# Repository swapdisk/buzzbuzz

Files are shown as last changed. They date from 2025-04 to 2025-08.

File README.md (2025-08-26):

# Game Show Buzzer Buttons

Just some files and code we used to mod these toy game show buzzer buttons. Not polished or even presentable for now. We'll make it better before we scale up production!

Each button connects using Bluetooth to the laptop presenting the game show. When a button is pressed, a keyboard event is sent, triggering a custom keyboard shortcut that runs the [`buzzer.sh`](./buzzer.sh) script. 

When activated, the script plays the buzzer sound and then uses [`hudkit`](https://github.com/anko/hudkit) to pop up an overlay on the laptop display showing which team buzzed in first. The buzz in from the losing team updates the overlay displaying the time difference.

## Photos

Behold our finished buzzer buttons being demonstrated with an example game show.
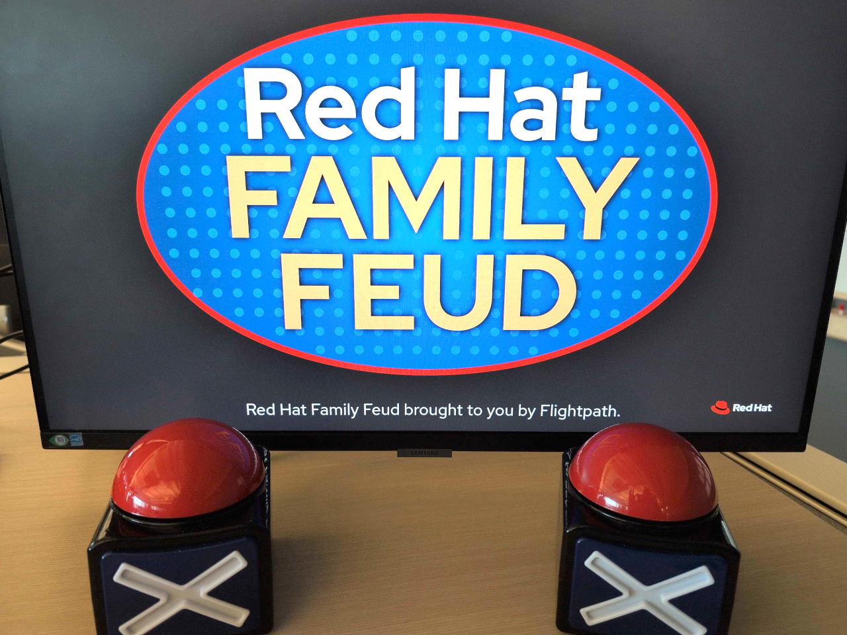
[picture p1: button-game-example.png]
Example game show use case


The back panel of each button sports a power switch that also serves as a Bluetooth pairing status indicator. Next to that is a USB-C port used for charging the internal battery.
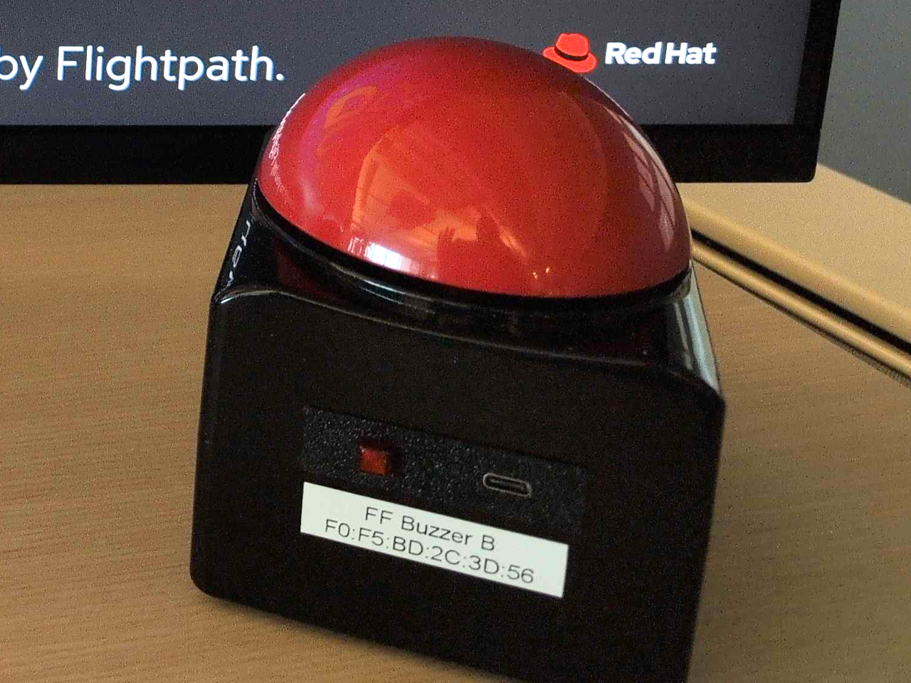
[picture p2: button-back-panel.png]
Back panel with power switch, status indicator and charging port


Here is a screenshot from [OpenSCAD](https://openscad.org/) showing the solid model used to 3D print the back panel and ESP32 card slot.
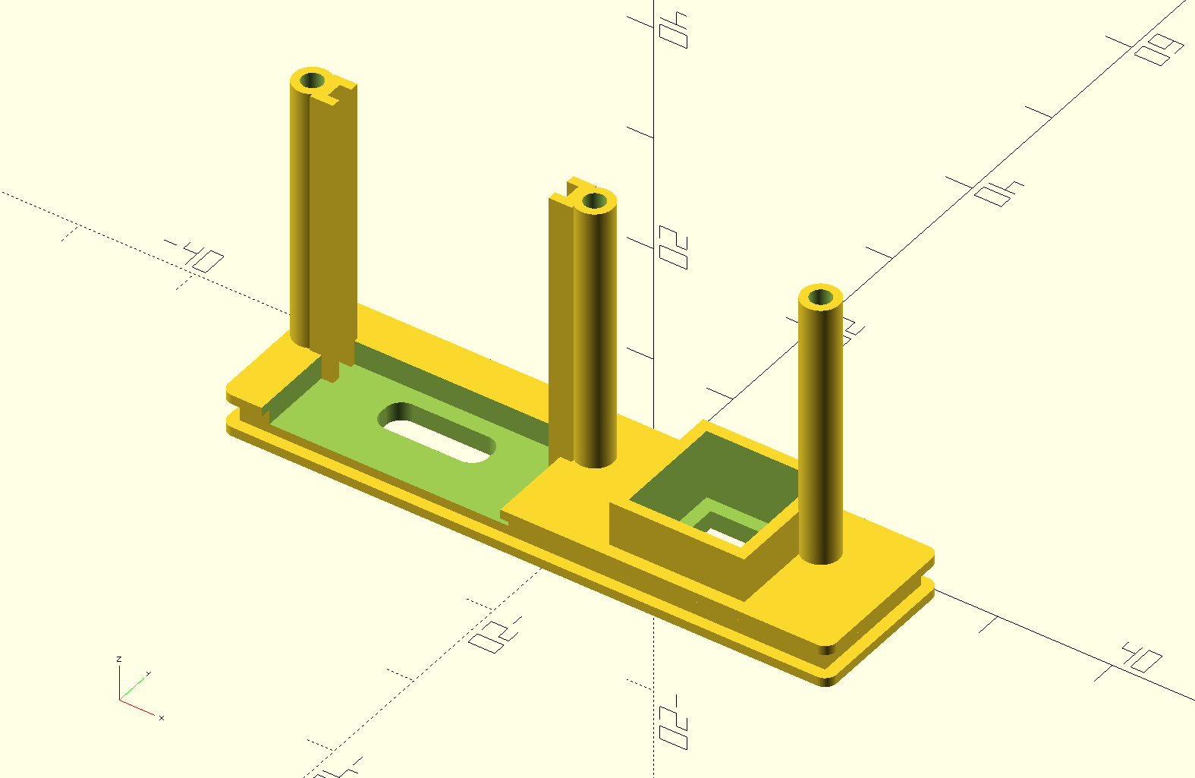
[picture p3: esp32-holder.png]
3D model of back panel with ESP32 card slot


## Licensing

MIT

See [LICENSE](LICENSE) to see the full text.

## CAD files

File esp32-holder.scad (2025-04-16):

$fn=120;

// face plate thick
fpt=0.80;
// face plate height
fph=14;
// face plate width
fpw=28;
// switch plate width
spw=28;
// face plate corner rad
fpc=1.0   ;
// slot thick
st=2.10;
// usb high
uh=1.60;
// board width
bw=20.80;
// board height
bh=25.10;
// usb dims
usbh=3.43; usbw=9.36; usbr=1.4;
// switch hole square
sh=7.45;
// switch hole depth
shd=1.55;
// switch body square
sb=9.78;

translate([-25, 0, 0]) difference() {
    union() {
        // switch plate front
        linear_extrude(fpt) hull() {
            translate([fpc, fpc, 0]) circle(fpc);
            translate([-fpc+spw, fpc, 0]) circle(fpc);
            translate([fpc, -fpc+fph, 0]) circle(fpc);
            translate([-fpc+spw, -fpc+fph, 0]) circle(fpc);
        }
        
        // slot rectangle
        translate([fpc, fpc, fpt]) cube([spw-fpc*2, fph-fpc*2, st]);
        
        // switch plate back
        translate([0, 0, fpt+st]) linear_extrude(fpt) hull() {
            translate([fpc, fpc, 0]) circle(fpc);
            translate([-fpc+spw, fpc, 0]) circle(fpc);
            translate([fpc, -fpc+fph, 0]) circle(fpc);
            translate([-fpc+spw, -fpc+fph, 0]) circle(fpc);
        }
        
        // switch support
        translate([(spw-sb-2)/2, (fph-sb-2)/2, shd]) cube([sb+2, sb+2, 6]);
    }
    
    // switch cavity
    translate([(spw-sh)/2, (fph-sh)/2, -1]) cube([sh, sh, 99]);
    translate([(spw-sb)/2, (fph-sb)/2, shd]) cube([sb, sb, 99]);
}

difference() {
    union() {
        // face plate front
        linear_extrude(fpt) hull() {
            translate([fpc, fpc, 0]) circle(fpc);
            translate([-fpc+fpw, fpc, 0]) circle(fpc);
            translate([fpc, -fpc+fph, 0]) circle(fpc);
            translate([-fpc+fpw, -fpc+fph, 0]) circle(fpc);
        }
        
        // slot rectangle
        translate([fpc, fpc, fpt]) cube([fpw-fpc*2, fph-fpc*2, st]);
        
        // face plate back
        translate([0, 0, fpt+st]) linear_extrude(fpt) hull() {
            translate([fpc, fpc, 0]) circle(fpc);
            translate([-fpc+fpw, fpc, 0]) circle(fpc);
            translate([fpc, -fpc+fph, 0]) circle(fpc);
            translate([-fpc+fpw, -fpc+fph, 0]) circle(fpc);
        }
    }
    
    // usb-c connector
    translate([(fpw-usbw)/2, (fph-usbh)/2, -1]) linear_extrude(99) hull() {
        translate([usbr, usbr, 0]) circle(usbr);
        translate([-usbr+usbw, usbr, 0]) circle(usbr);
        translate([usbr, -usbr+usbh, 0]) circle(usbr);
        translate([-usbr+usbw, -usbr+usbh, 0]) circle(usbr);
    }

    // board cavity
    translate([(fpw-bw)/2, -1.5+(fph-usbh)/2, uh]) cube([bw, 99, 99]);

    // debug
    //translate([0, 0, -1]) cube(5);
}

// board frame
aj=0.4+(fph-10)/2;
translate([-1.0+(fpw-bw)/2, fpc+aj, uh]) cube([1, 3.1, bh]);
translate([(fpw-bw)/2, fpc+aj, uh]) cube([1, 0.8, bh]);
translate([(fpw-bw)/2, fpc+2.3+aj, uh]) cube([1, 0.8, bh]);

translate([(fpw+bw)/2, fpc+aj, uh]) cube([1, 3.1, bh]);
translate([-1.0+(fpw+bw)/2, fpc+aj, uh]) cube([1, 0.8, bh]);
translate([-1.0+(fpw+bw)/2, fpc+2.3+aj, uh]) cube([1, 0.8, bh]);

// screw columns
c1=1.6;
c2=0.9;
translate([-1.9+(fpw-bw)/2, fpc+aj+1.5, uh]) difference() {
    cylinder(bh, c1, c1);
    cylinder(bh+1, c2, c2);
}
translate([1.9+(fpw+bw)/2, fpc+aj+1.5, uh+2]) difference() {
    cylinder(bh-2, c1, c1);
    cylinder(bh+1, c2, c2);
}
translate([-18, fpc+aj+1.5, uh]) difference() {
    cylinder(bh, c1, c1);
    cylinder(bh+1, c2, c2);
}
echo(-1.9+(fpw-bw)/2, 1.9+(fpw+bw)/2, -18);

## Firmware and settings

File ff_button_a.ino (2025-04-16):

/* 
 * Sample program for ESP32 acting as a Bluetooth keyboard
 * 
 * Copyright (c) 2019 Manuel Bl
 * 
 * Licensed under MIT License
 * https://opensource.org/licenses/MIT
 */

//
// This program lets an ESP32 act as a keyboard connected via Bluetooth.
// When a button attached to the ESP32 is pressed, it will generate the key strokes for a message.
//
// For the setup, a momentary button should be connected to pin 2 and to ground.
// Pin 2 will be configured as an input with pull-up.
//
// In order to receive the message, add the ESP32 as a Bluetooth keyboard of your computer
// or mobile phone:
//
// 1. Go to your computers/phones settings
// 2. Ensure Bluetooth is turned on
// 3. Scan for Bluetooth devices
// 4. Connect to the device called "ESP32 Keyboard"
// 5. Open an empty document in a text editor
// 6. Press the button attached to the ESP32

#define US_KEYBOARD 1

#include "BLEDevice.h"
#include "BLEHIDDevice.h"
#include "HIDTypes.h"
#include "HIDKeyboardTypes.h"


// Change the below values if desired
#define BUTTON_PIN 6
#define MESSAGE "a"
#define DEVICE_NAME "FF Buzzer A"
#define STATUS_LED 7

// Debounce and battery report timers
unsigned long debounceTime = 3000;
unsigned long lastBuzz = debounceTime;
unsigned long battReportTime = 15000;
unsigned long lastBattReport = battReportTime;
unsigned long nowTime;

// Return battery level as percent
int battLevel() {
  int battPct = (analogReadMilliVolts(0) - 1850) * 100 / 250;
  return ((battPct < 0) ? 0 : (battPct > 100) ? 100 : battPct);
}


// Forward declarations
void bluetoothTask(void*);
void typeText(const char* text);


bool isBleConnected = false;


void setup() {
    Serial.begin(115200);

    // Configure GPIO pins
    analogReadResolution(12);
    pinMode(BUTTON_PIN, INPUT_PULLUP);
    pinMode(STATUS_LED, OUTPUT);
    digitalWrite(STATUS_LED, HIGH);

    // start Bluetooth task
    xTaskCreate(bluetoothTask, "bluetooth", 20000, NULL, 5, NULL);
}


void loop() {
  // Get current timestamp
  nowTime = millis();

  // Bluetooth keyboard event
  if (isBleConnected && digitalRead(BUTTON_PIN) == LOW) {
    if (nowTime - lastBuzz > debounceTime) {
      // Debug output
      Serial.print("Sending keypress at ");
      Serial.println(nowTime);

      // Send key press and release events
      typeKustom(MESSAGE);
    }

    // Reset debounce timer
    lastBuzz = nowTime;
  }

  // Status blink logic
  // Slow short blink: Bluetooth connected
  // Quick long blink: Waiting for connection
  if (isBleConnected) {
    digitalWrite(STATUS_LED, (nowTime % 1500 > 100) ? LOW : HIGH);
  } else {
    digitalWrite(STATUS_LED, (nowTime % 500 > 400) ? LOW : HIGH);
  }
}


// Message (report) sent when a key is pressed or released
struct InputReport {
    uint8_t modifiers;	     // bitmask: CTRL = 1, SHIFT = 2, ALT = 4
    uint8_t reserved;        // must be 0
    uint8_t pressedKeys[6];  // up to six concurrenlty pressed keys
};

// Message (report) received when an LED's state changed
struct OutputReport {
    uint8_t leds;            // bitmask: num lock = 1, caps lock = 2, scroll lock = 4, compose = 8, kana = 16
};


// The report map describes the HID device (a keyboard in this case) and
// the messages (reports in HID terms) sent and received.
static const uint8_t REPORT_MAP[] = {
    USAGE_PAGE(1),      0x01,       // Generic Desktop Controls
    USAGE(1),           0x06,       // Keyboard
    COLLECTION(1),      0x01,       // Application
    REPORT_ID(1),       0x01,       //   Report ID (1)
    USAGE_PAGE(1),      0x07,       //   Keyboard/Keypad
    USAGE_MINIMUM(1),   0xE0,       //   Keyboard Left Control
    USAGE_MAXIMUM(1),   0xE7,       //   Keyboard Right Control
    LOGICAL_MINIMUM(1), 0x00,       //   Each bit is either 0 or 1
    LOGICAL_MAXIMUM(1), 0x01,
    REPORT_COUNT(1),    0x08,       //   8 bits for the modifier keys
    REPORT_SIZE(1),     0x01,       
    HIDINPUT(1),        0x02,       //   Data, Var, Abs
    REPORT_COUNT(1),    0x01,       //   1 byte (unused)
    REPORT_SIZE(1),     0x08,
    HIDINPUT(1),        0x01,       //   Const, Array, Abs
    REPORT_COUNT(1),    0x06,       //   6 bytes (for up to 6 concurrently pressed keys)
    REPORT_SIZE(1),     0x08,
    LOGICAL_MINIMUM(1), 0x00,
    LOGICAL_MAXIMUM(1), 0x65,       //   101 keys
    USAGE_MINIMUM(1),   0x00,
    USAGE_MAXIMUM(1),   0x65,
    HIDINPUT(1),        0x00,       //   Data, Array, Abs
    REPORT_COUNT(1),    0x05,       //   5 bits (Num lock, Caps lock, Scroll lock, Compose, Kana)
    REPORT_SIZE(1),     0x01,
    USAGE_PAGE(1),      0x08,       //   LEDs
    USAGE_MINIMUM(1),   0x01,       //   Num Lock
    USAGE_MAXIMUM(1),   0x05,       //   Kana
    LOGICAL_MINIMUM(1), 0x00,
    LOGICAL_MAXIMUM(1), 0x01,
    HIDOUTPUT(1),       0x02,       //   Data, Var, Abs
    REPORT_COUNT(1),    0x01,       //   3 bits (Padding)
    REPORT_SIZE(1),     0x03,
    HIDOUTPUT(1),       0x01,       //   Const, Array, Abs
    END_COLLECTION(0)               // End application collection
};


BLEHIDDevice* hid;
BLECharacteristic* input;
BLECharacteristic* output;

const InputReport NO_KEY_PRESSED = { };


/*
 * Callbacks related to BLE connection
 */
class BleKeyboardCallbacks : public BLEServerCallbacks {

    void onConnect(BLEServer* server) {
        isBleConnected = true;

        // Allow notifications for characteristics
        BLE2902* cccDesc = (BLE2902*)input->getDescriptorByUUID(BLEUUID((uint16_t)0x2902));
        cccDesc->setNotifications(true);

        Serial.println("Client has connected");
    }

    void onDisconnect(BLEServer* server) {
        isBleConnected = false;

        // Disallow notifications for characteristics
        BLE2902* cccDesc = (BLE2902*)input->getDescriptorByUUID(BLEUUID((uint16_t)0x2902));
        cccDesc->setNotifications(false);

        Serial.println("Client has disconnected");
    }
};


/*
 * Called when the client (computer, smart phone) wants to turn on or off
 * the LEDs in the keyboard.
 * 
 * bit 0 - NUM LOCK
 * bit 1 - CAPS LOCK
 * bit 2 - SCROLL LOCK
 */
 class OutputCallbacks : public BLECharacteristicCallbacks {
    void onWrite(BLECharacteristic* characteristic) {
        OutputReport* report = (OutputReport*) characteristic->getData();
        Serial.print("LED state: ");
        Serial.print((int) report->leds);
        Serial.println();
    }
};


void bluetoothTask(void*) {

    // initialize the device
    BLEDevice::init(DEVICE_NAME);
    BLEServer* server = BLEDevice::createServer();
    server->setCallbacks(new BleKeyboardCallbacks());

    // create an HID device
    hid = new BLEHIDDevice(server);
    input = hid->inputReport(1); // report ID
    output = hid->outputReport(1); // report ID
    output->setCallbacks(new OutputCallbacks());

    // set manufacturer name
    hid->manufacturer()->setValue("Maker Community");
    // set USB vendor and product ID
    hid->pnp(0x02, 0xe502, 0xa111, 0x0210);
    // information about HID device: device is not localized, device can be connected
    hid->hidInfo(0x00, 0x02);

    // Security: device requires bonding
    BLESecurity* security = new BLESecurity();
    security->setAuthenticationMode(ESP_LE_AUTH_BOND);

    // set report map
    hid->reportMap((uint8_t*)REPORT_MAP, sizeof(REPORT_MAP));
    hid->startServices();

    // advertise the services
    BLEAdvertising* advertising = server->getAdvertising();
    advertising->setAppearance(HID_KEYBOARD);
    advertising->addServiceUUID(hid->hidService()->getUUID());
    advertising->addServiceUUID(hid->deviceInfo()->getUUID());
    advertising->addServiceUUID(hid->batteryService()->getUUID());
    advertising->start();

    Serial.println("BLE ready");
    
    while(true) {
      int bl = battLevel();
      int anaread = analogRead(0);
      int anamv = analogReadMilliVolts(0);

      // Debug output
      Serial.print("Battery % ");
      Serial.print(bl);
      Serial.print(", anaread/mv ");
      Serial.print(anaread);
      Serial.print("/");
      Serial.print(anamv);
      Serial.print(", diff ");
      Serial.print(anamv - anaread);
      Serial.print(", mv ");
      Serial.println(anamv * 2);

      // Update battery level
      hid->setBatteryLevel(bl);

      delay(battReportTime);
    }
    
    delay(portMAX_DELAY);
};


void typeText(const char* text) {
    int len = strlen(text);
    for (int i = 0; i < len; i++) {

        // translate character to key combination
        uint8_t val = (uint8_t)text[i];
        if (val > KEYMAP_SIZE)
            continue; // character not available on keyboard - skip
        KEYMAP map = keymap[val];

        // create input report
        InputReport report = {
            .modifiers = map.modifier,
            .reserved = 0,
            .pressedKeys = {
                map.usage,
                0, 0, 0, 0, 0
            }
        };

        // send the input report
        input->setValue((uint8_t*)&report, sizeof(report));
        input->notify();

        delay(5);

        // release all keys between two characters; otherwise two identical
        // consecutive characters are treated as just one key press
        input->setValue((uint8_t*)&NO_KEY_PRESSED, sizeof(NO_KEY_PRESSED));
        input->notify();

        delay(5);
    }
}

void typeKustom(const char* text) {
    int len = strlen(text);
    for (int i = 0; i < len; i++) {

        // translate character to key combination
        uint8_t val = (uint8_t)text[i];
        if (val > KEYMAP_SIZE)
            continue; // character not available on keyboard - skip
        KEYMAP map = keymap[val];

        // create input report
        InputReport report = {
            .modifiers = 5, // CTRL + ALT
            .reserved = 0,
            .pressedKeys = {
                map.usage,
                0, 0, 0, 0, 0
            }
        };

        // send the input report
        input->setValue((uint8_t*)&report, sizeof(report));
        input->notify();

        delay(5);

        // release all keys between two characters; otherwise two identical
        // consecutive characters are treated as just one key press
        input->setValue((uint8_t*)&NO_KEY_PRESSED, sizeof(NO_KEY_PRESSED));
        input->notify();

        delay(5);
    }
}
